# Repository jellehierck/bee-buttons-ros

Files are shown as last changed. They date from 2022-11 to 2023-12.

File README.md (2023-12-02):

# Bee Button

These are the bee buttons, these buttons can be controlled with the use of MQTT.
They send u if they have been pressed, double pressed or long pressed. And in turn, U can tell them to do light effects or play music. You controll the buttons via serial commandos, which every programming language supports. All files related to the project can be found on [project files](https://github.com/utwente-interaction-lab/Bee-Buttons). A more detailed guide can be found at [guide](https://github.com/utwente-interaction-lab/Interaction-buttons). If u have any questions please mail to m.c.pijnappel@student.utwente.nl.

### Mesh Dongle

The commands that you want to send to the mesh go via the Mesh dongle. You can send the commands over serial to this dongle with a baudrate of 115200. The screen on the fongle tells some basic information about the mesh it is connected to. It also tells how many buttons are connected to it.

### Normal Button

- Blinking Red -> Not connected to the mesh.
- Blinking Green -> Connected to Mesh.

## SD card

On the SD card, there are a few things.

- Folder "Sounds": here u can store ur **MP3** sound files that u want to play.
- config.txt: Here are some configs u can change related to networking and some default parameters, without having to upload new code.
- README.md: that is what u are reading at the moment.
- Firmware.bin: it is not on there at the moment, but u can update the firmware by putting a firmware.bin file on the SD card.

### config.txt

The config file is meant to quickly change some things without needing to edit the code.

- **MESH_SSID**: This is the name of the mesh, which has to match among the buttons u use, otherwise, they cannot find each other. U can also see this with ur phone/computer, but u cannot connect to it without a special app.
- **MESH_PASSWORD**: This is the password your network will use between the buttons, so not ur laptop. This also has to match between the buttons.
- **MESH_PORT**: This is the port where they communicate and also has to match. U can have multiple networks match on the MESH_SSID and MESH_PASWORD, but change the port. They won't be able to communicate with each other that way.
- **Volume**: This is the volume level the button start with. The scale is 1-21, can be handy to change this on startup. It can also be changed later with MQTT commands, but it won't be remembered between startups.
- **BRIGHTNESS**: The brightness value the LEDs start with, the value is in a range between 0 and 255. Just as with the volume, u can change this with a command but it will not be remembered between reboots.

## Commands

These are all the commands that are available for the buttons with the use of serial commands. You start with either a nodeid which you can request with a command, or with 'Broadcast'. This can be used to send a commando to all nodes or to a specific node. After this you send ':' and the commando you want to send. Between each command layer you also put a ':'. At the end of command you have to put a '`' to indicate the command is done.

A command can be 'Broadcast:Full:Purple`', this will turn all connected buttons purple. To test command you can use the serial monitor from for example the arduino IDE.

### nodelist

To get a list off all nodes connected to the dongle you can send the command 'nodelist`'. This will return a string that start with ''nodeList' followed by all the nodes seperated by a '/'. For example 'nodeList/498425705/3171683153' The first id is from the dongle itself and can be ignored. This this list contains only the button with id 3171683153.

### Colors

These colors are available to use.

- Red
- Blue
- Green
- Purple
- Yellow
- Orange
- Cyan
- Pink

These are the commands;

- `:Play:[song]` - This is how u play a song on a button. [song] has to be replaced with the name of a song u have put in the sounds folder of the SD card without the ".mp3".
- `:Rainbow` - This will put a rainbow effect on the button.
- `:Full:[color]` - This will put a solid color on the button. Replace [color] with one of the colors.
- `:Circle:[color]` - This will put a circle effect on the button in a color.
- `:Blink:[color]` - This will have the button blink a color.
- `:Clear` - Turns of the LEDs.
- `:Brightness` - With this, u can change the brightness of the button on a scale from 0 - 255.
- `:Volume` - With this u can change the volume of the speaker on a scale from 0-21.
- `:Battery:[subcommand]` - With this, u can get information about the battery.
  - `Percentage` - Gives the battery percentage.
  - `Voltage` - Gives the battery voltage.
  - `Show` - Gives back the battery voltage and percentage, but also show the battery capacity with the LEDs. 

## Extra pins available  in the buttons

When u screw open the button there are some pins extra available to use. U do have to edit the code to use them. The code is written with platformIO and the code is on the GitHub. Installing [platformio](https://platformio.org/) is fairly easy with Visual Studio Code.

- IC3/IC4: These are pins for the I2C protocol, lots of digital sensors can be connected to these pins like accelerometer/gyroscope. 
- Analoge Pins: If u want to do something analoge it can be done with these pins. Make sure it is all 3.3V, since that is what the controller has, has maximum input and supplies.
- LED Strip PINS: If u want to use more LEDs u can connect a neopixel/ws2812b strip on these pins. At the moment this might not work with every buttons since some LEDs are broken and might not pass on the signal to the end. The LED strip would be LED number 13. But in the case of some buttons this might be off since some jumper wires are soldered over LEDs.

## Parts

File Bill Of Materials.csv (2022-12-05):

What | How Many Per Button | How Many Per Package | Where From | Product Number | Link
Accu 1250mAh | 1 | 1 | opencircuits | n.v.t. | https://opencircuit.shop/product/lithium-ion-polymer-batterij-3.7v-1250mah-jst
Threaded inserts M3 | 6 | 100 | RS Components | 204-0616 | https://nl.rs-online.com/web/p/threaded-inserts/2040616
Screws 10mm M3 | 3 | 100 | RS Components | 560-596 | https://nl.rs-online.com/web/p/machine-screws/0560596
Screws 30mm M3 | 3 | 100 | RS Components | 560-647 | https://nl.rs-online.com/web/p/machine-screws/0560647
Speakers | 1 | 1 | RS Components | 754-2090 | https://nl.rs-online.com/web/p/miniature-speakers/7542090
dfRobot firebeetle micro controller | 1 | 1 | TinyTronics | SKU:004013 | https://www.tinytronics.nl/shop/en/development-boards/microcontroller-boards/with-wi-fi/dfrobot-firebeetle-esp32-iot-microcontroller-wi-fi-and-bluetooth-seper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
Springs | 3 | Depends on order size | ALCOMEX | D1500 | https://webshop.alcomex.nl/drukveer-vst-o-0-63x6-30x11-50-mm-d1500
anti slip pads | 3 | 75 | RS Components | 173-5963 | https://nl.rs-online.com/web/p/anti-slip-pads/1735963
Micro SD card 32GB | 1 | 1 | IAPC
PCB | 1 | Depends on order size | JLCPCB
White Plexiglass 3mm | 1 window | n.v.t. | kunstofplatenshop.nl
3D print Filament | 5 parts | 6 per kilo
Hook & Loop Tape | 1 strip | 5m per rol | RS Components | 890-4159 | https://nl.rs-online.com/web/p/hook-loop-tapes/8904159

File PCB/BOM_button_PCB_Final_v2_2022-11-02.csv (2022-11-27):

ID | Name | Designator | Footprint | Quantity | Manufacturer Part | Manufacturer | Supplier | Supplier Part | Price
1 | 100nF | C005,C006,C007,C008,C009,C010,C011,C012,C001,C002,C003,C004 | C0603 | 12 | CC0603KRX7R9BB104 | YAGEO | LCSC | C14663 | 0.002
2 | WS2812B-MINI | LED005,LED006,LED007,LED008,LED009,LED010,LED011,LED012,LED001,LED002,LED003,LED004 | LED-SMD_4P-L3.5-W3.5-TL_WS2812B | 12 | WS2812B-Mini | Worldsemi | LCSC | C527089 | 0.111
3 | TF PUSH | CARD2 | TF-SMD_TF-PUSH | 1 | TF PUSH | SHOU HAN | LCSC | C393941 | 0.047
4 | UK-B0224-G9.5-250 | BUTTON | SW-TH_4P-L12.0-W12.0-P5.00-LS12.5 | 1 | UK-B0224-G9.5-250 | USAKRO | LCSC | C10861 | 0.052
5 | 220pF | C5,C6 | C0805 | 2 | CL21B221KBANNNC | SAMSUNG | LCSC | C53172 | 0.01
6 | 10uF | C7 | C0805 | 1 | CL21A106KAYNNNE | SAMSUNG | LCSC | C15850 | 0.011
7 | 100nF | C8 | C0805 | 1 | CC0805KRX7R9BB104 | YAGEO | LCSC | C49678 | 0.004
8 | Ferrite | L3,L4 | L0603 | 2 | BLM18KG601SH1D | muRata(村田) | LCSC | C710379 | 0.02
9 | 1MΩ | R1 | R0805 | 1 | 0805W8F1004T5E | UniOhm | LCSC | C17514 | 0.002
10 | R2_Divider | R3 | R0805 | 1 | 0805W8F3003T5E | UniOhm | LCSC | C17616 | 0.002
11 | R1_Divider | R4 | R0805 | 1 | 0805W8F2003T5E | UniOhm | LCSC | C17539 | 0.002
12 | SS-12D06L5 | SLIDESWITCH | SW-TH_3P-P4.70_L11.1-W12.7 | 1 | SS-12D06L5 | XKB Enterprise | LCSC | C319015 | 0.347
13 | MAX98357AETE+T | U3 | TQFN-16_L3.0-W3.0-P0.50-BL-EP1.5 | 1 | MAX98357AETE+T | MAXIM(美信) | LCSC | C910544 | 1.208

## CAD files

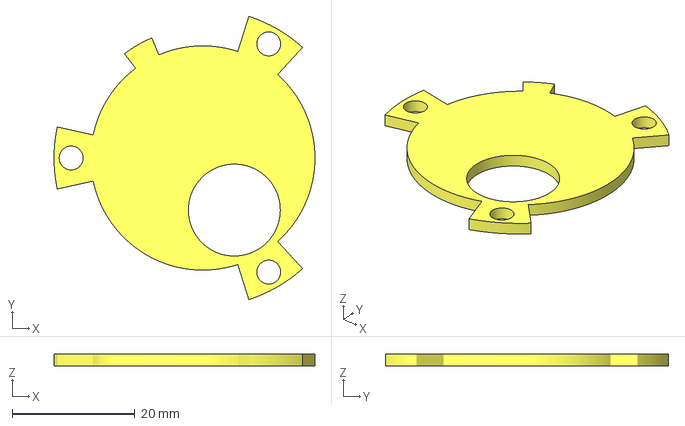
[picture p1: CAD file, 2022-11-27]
3D Models/3mf/SpeakerLid.3mf
42.6 x 46.2 x 2.00 mm

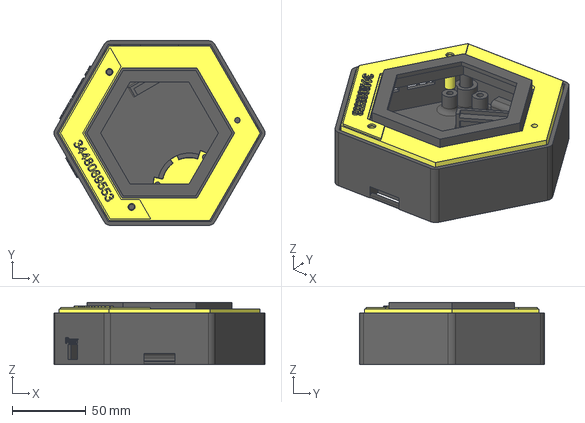
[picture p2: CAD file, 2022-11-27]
3D Models/Bee Buttons Housing.step
142.8 x 125.1 x 42.0 mm

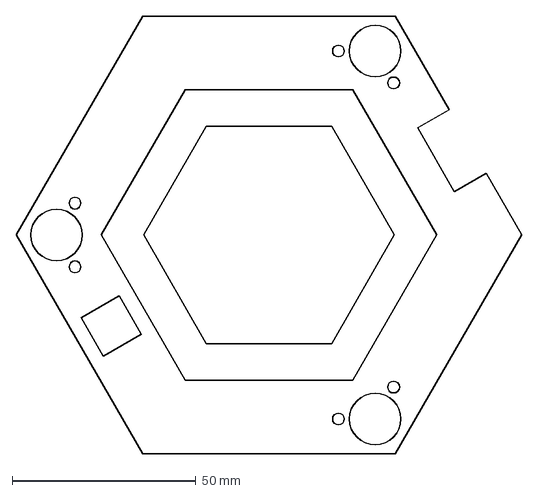
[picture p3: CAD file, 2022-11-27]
PCB/PCB_outline.dxf
137.4 x 119.0 mm

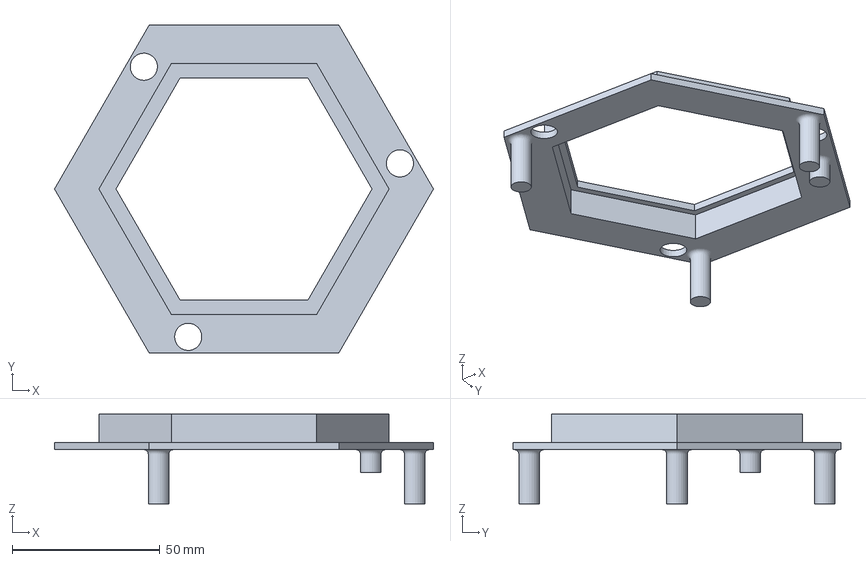
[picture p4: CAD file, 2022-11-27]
3D Models/3mf/Mid.3mf
128.2 x 111.0 x 30.3 mm

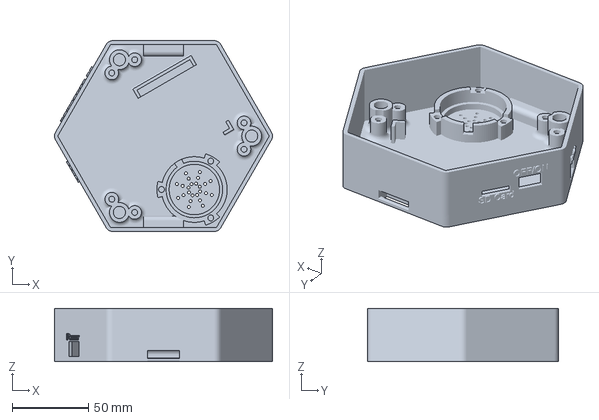
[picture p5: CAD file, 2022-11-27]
3D Models/3mf/Bottom.3mf
142.8 x 125.1 x 35.0 mm

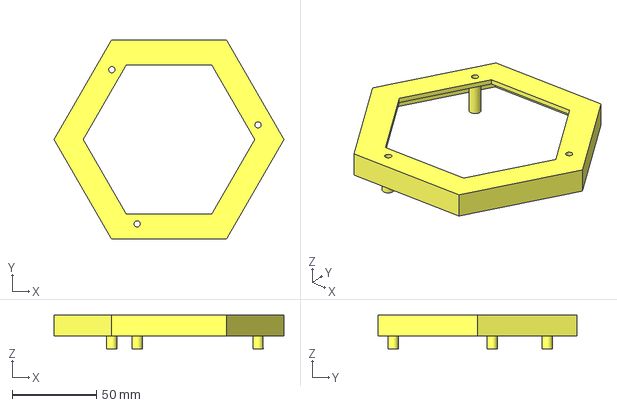
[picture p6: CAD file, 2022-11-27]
3D Models/3mf/Top.3mf
136.3 x 118.0 x 20.0 mm

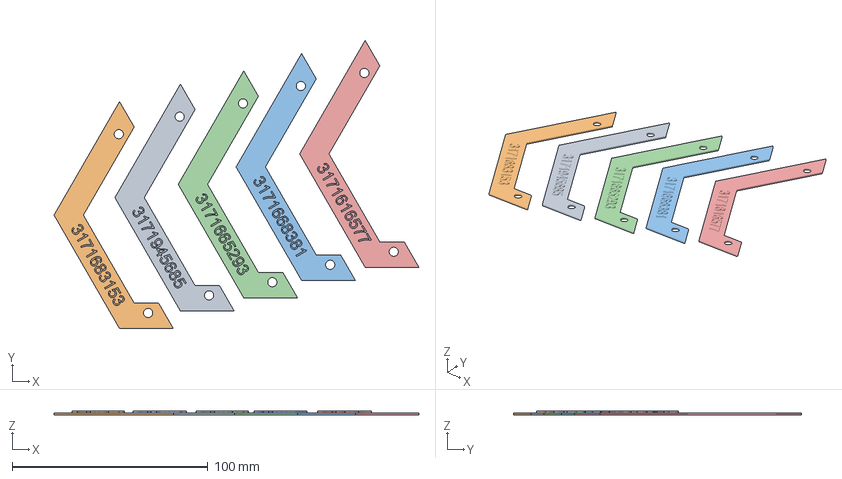
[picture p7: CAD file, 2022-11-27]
3D Models/ID Plate/Blauw_Wit.3mf
186.5 x 147.3 x 2.00 mm

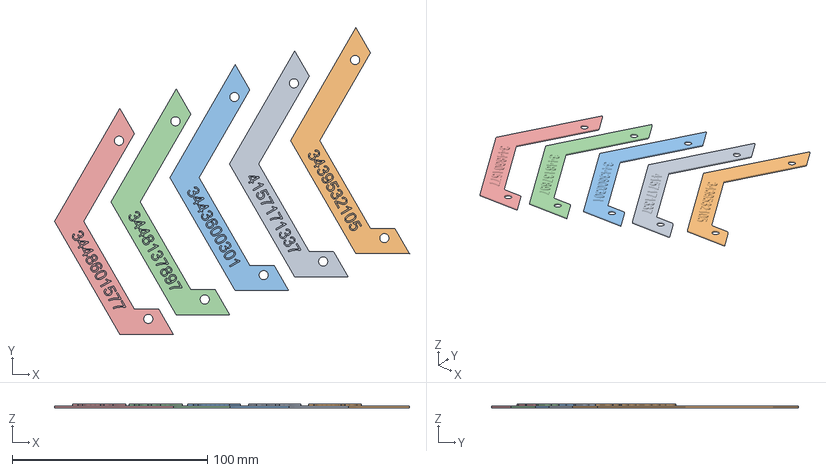
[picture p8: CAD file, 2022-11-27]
3D Models/ID Plate/Zwart_Rood.3mf
182.0 x 157.4 x 2.00 mm

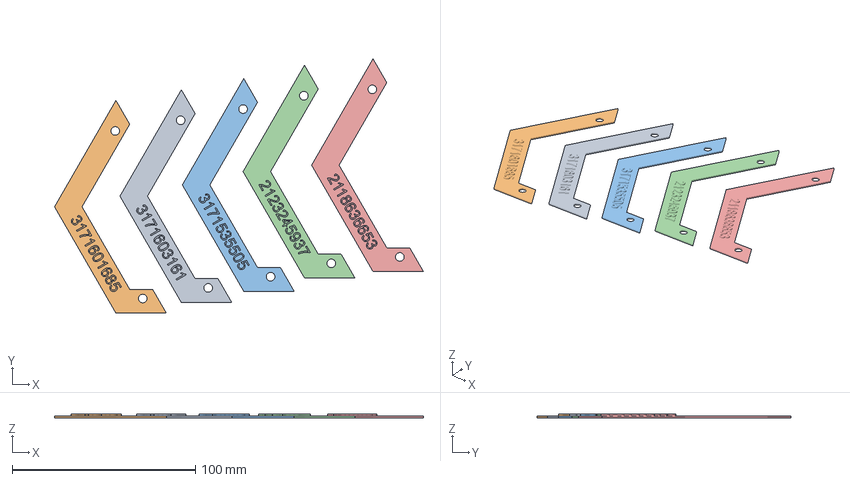
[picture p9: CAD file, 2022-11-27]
3D Models/ID Plate/Wit_Blauw.3mf
201.1 x 138.7 x 2.00 mm

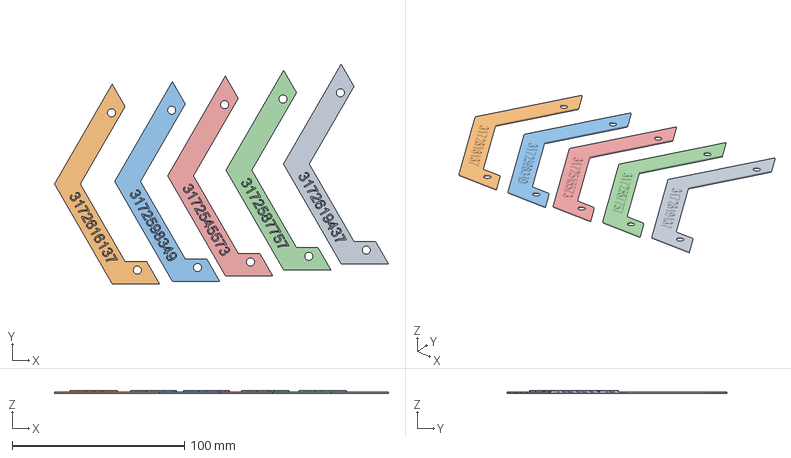
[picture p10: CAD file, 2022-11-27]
3D Models/ID Plate/Rood_Zwart.3mf
193.9 x 127.6 x 2.00 mm

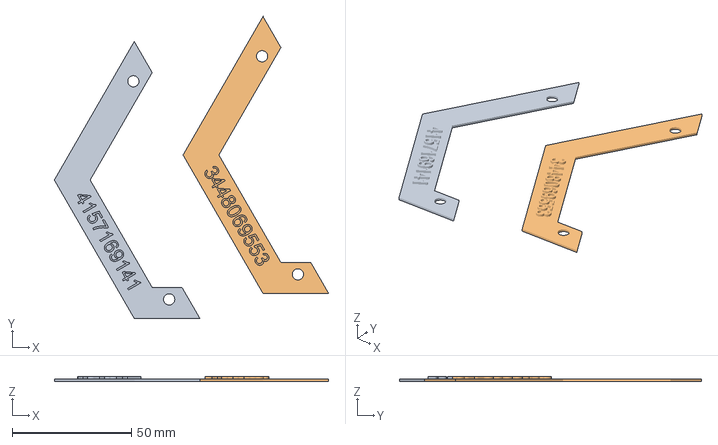
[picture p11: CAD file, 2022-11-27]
3D Models/ID Plate/Blauw_Wit_2.3mf
114.9 x 126.5 x 2.00 mm

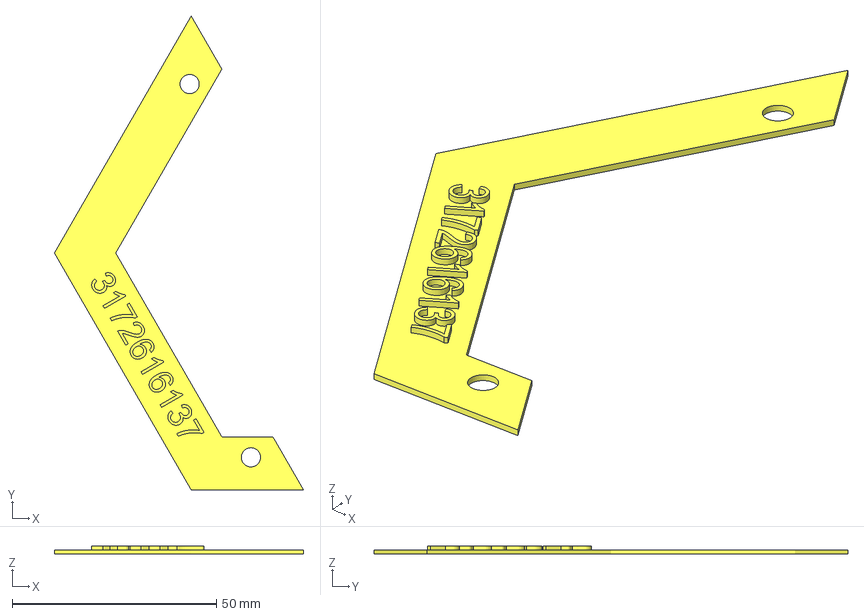
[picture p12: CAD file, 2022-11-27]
3D Models/ID Plate/3172616137.3mf
61.0 x 116.0 x 2.00 mm

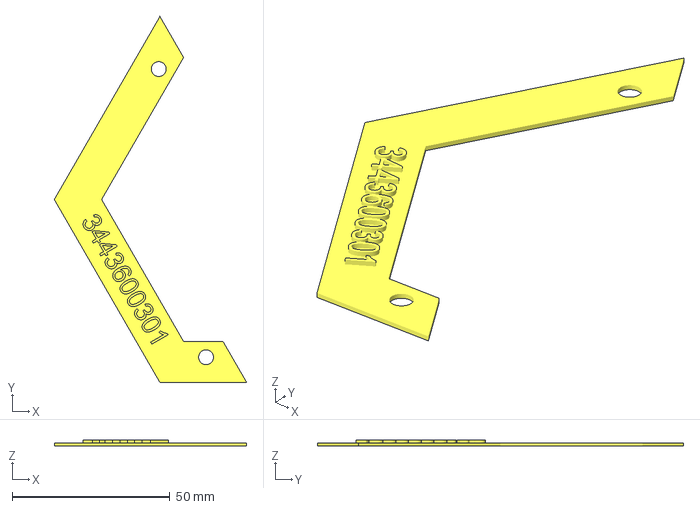
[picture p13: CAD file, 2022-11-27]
3D Models/ID Plate/3443600301.3mf
61.0 x 116.0 x 2.00 mm

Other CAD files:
3D Models/ID Plate/3448601577.3mf
3D Models/ID Plate/3171945685.3mf
3D Models/ID Plate/4157169141.3mf
3D Models/ID Plate/3171668381.3mf
3D Models/ID Plate/3172545573.3mf
3D Models/Bee Buttons Housing.f3d
3D Models/ID Plate/2118599505.3mf
3D Models/ID Plate/2118636653.3mf
3D Models/ID Plate/2123245937.3mf
3D Models/ID Plate/3171535505.3mf
3D Models/ID Plate/3171601685.3mf
3D Models/ID Plate/3171603161.3mf
3D Models/ID Plate/3171616577.3mf
3D Models/ID Plate/3171665293.3mf
3D Models/ID Plate/3171683153.3mf
3D Models/ID Plate/3172587757.3mf
3D Models/ID Plate/3172598349.3mf
3D Models/ID Plate/3172619437.3mf
3D Models/ID Plate/3439532105.3mf
3D Models/ID Plate/3448069553.3mf
3D Models/ID Plate/3448137897.3mf
3D Models/ID Plate/4157171337.3mf
3D Models/STL/Bottom.stl
3D Models/STL/Mid.stl
3D Models/STL/SpeakerLid.stl
3D Models/STL/Top.stl

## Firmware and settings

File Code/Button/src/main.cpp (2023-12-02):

// Main file of the code
// dont put extra delays anywhere, this will break the networking part of the buttons

#include <Arduino.h>
#include "general.h"

#include "painlessmeshfiles.h"
#include "audiofiles.h"
#include "button.h"
#include "lights.h"
#include "sdCard.h"
#include <ArduinoJson.h>
#include "battery.h"
Config config;


// setup of all functions and button parts are called here
void setup()
{

  Serial.begin(115200);
  delay(2000);
  pinMode(LED_BUILTIN, OUTPUT);
  digitalWrite(LED_BUILTIN, LOW);
  SDCARD_SETUP();
  leds_setup();
  delay(1000);
  Update_Firmware();

  Serial.println(BatteryPercentage());
  // only lets the code run when the battery is full enough
  if (BatteryPercentage() > 2)
  {


    painlessmesh_setup();
    Serial.println("this is not the gateway!");
    BlinkMode("Red");

    if (String(config.Mesh_PASSWORD) == "ditisniettekort" & String(config.Mesh_SSID) == "test")
    {
      BlinkMode("Yellow");
    }

    audio_setup();

    button_setup();
  }
  else if (BatteryPercentage() < 3)
  {

    Show_Bat();
  }
}

// all functions that need be kept running are put here
void loop()
{
  leds_loop();
  // only leds the code run when the battery is full enough
  if (BatteryPercentage() > 2)
  {
    audio_loop();

    button_loop();
    // checks if a button is a gateway or just a normal button.
    mesh_loop();

  }
  else if (BatteryPercentage() < 3)
  {

    Show_Bat();
  }
}

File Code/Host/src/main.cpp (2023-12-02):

// Main file of the code
// dont put extra delays anywhere, this will break the networking part of the buttons

#include <Arduino.h>
#include "general.h"
#include "painlessmeshfiles.h"
#include "display.h"
#include "sdCard.h"
#include <ArduinoJson.h>
// #include "OneButton.h"
#include "button.h"

Config config;
int nodeCount = 0;
// #include "USB.h"

// void testdrawtext(char *text, uint16_t color);
// setup of all functions and button parts are called here
void setup()
{

  Serial.begin(115200);
  button_setup();
  setCpuFrequencyMhz(240);
  delay(2000);


  SDCARD_SETUP();


  delay(1000);
  Update_Firmware();
  displaySetup();

  painlessmesh_setup();
  Serial.println("This is the gateway");
  pinMode(0, INPUT);



}

// all functions that need be kept running are put here
void loop()
{
  button_loop();
  mesh_loop();

// Checks if there was a message on serial
  if (Serial.available())
  {
    String message = Serial.readStringUntil('`');

    if (message != "")
    {
      message.trim();
      
// parses the message received over Serial
      int nodeNumberindexEnd = message.indexOf(':');
      String nodeNumber = message.substring(0, nodeNumberindexEnd);
      String Command = message.substring(nodeNumberindexEnd);

// checks if the message has to go to every node on the network, a specific button or if the nodeList has to be send back
      if (nodeNumber == "Broadcast")
      {
        mesh.sendBroadcast(Command);
      }
      else if (nodeNumber == "Nodelist")
      {
        auto nodes = mesh.getNodeList(true);
        String str = "nodeList";
        nodeCount = -1;
        for (auto &&id : nodes)
        {
          str += String("/") + String(id);
          nodeCount = nodeCount + 1;
        }

        Serial.println(str);
        DisplayNode(nodeCount);
      }
      else
      {

        uint32_t nodeNumberInt = (nodeNumber.substring(0, 9).toInt() * 10) + nodeNumber.substring(9).toInt();
        mesh.sendSingle(nodeNumberInt, Command);
      }
    }
  }
}

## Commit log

2022-11-27 small changes to readme
    [config.txt]
2022-11-27 added fusion files
    [Bee Buttons Housing.f3d, Bee Buttons Housing.step, Bottom.3mf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]
2022-11-30 small changes to protocol
    [config.txt]
2022-12-02 added BOM
    [Bill Of Materials.csv]
2022-12-02 changed ; to ,
    [Bill Of Materials.csv]
2023-07-23 switch to serial
2023-12-02 all code updated
    [config.txt]
